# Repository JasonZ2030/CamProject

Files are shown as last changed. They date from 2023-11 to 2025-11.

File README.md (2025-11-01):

# Underwater Fishing Camera

## Introduction

As a shore angler, I've spent countless hours casting my line, waiting for bites that never came. The frustrating reality? I often had no idea if there were even any fish where I was casting. It didn't matter how good my lure was or how expensive my bait – if the fish weren't there, I wasn't catching anything.

Unlike anglers with boats who can afford expensive sonar fishfinders, I needed a budget-friendly solution that would work from the shore. That's when the idea hit me: why not create a small underwater camera that I could attach to my fishing line? This way, I could scout locations before wasting time fishing in empty water.

## Photos
<div style="display: flex; justify-content: space-around; margin: 20px 0;">
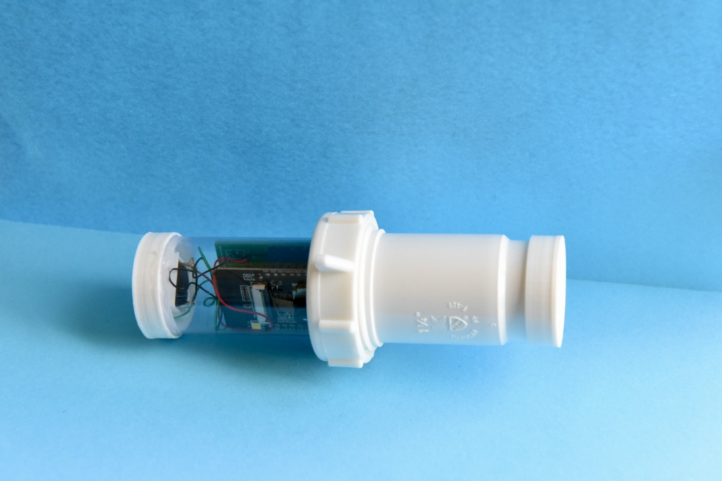
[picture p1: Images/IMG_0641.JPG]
  
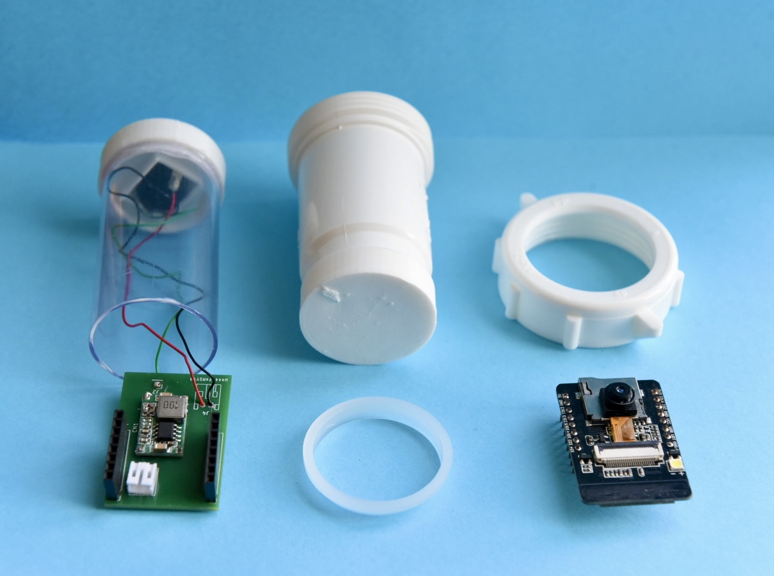
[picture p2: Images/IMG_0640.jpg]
  
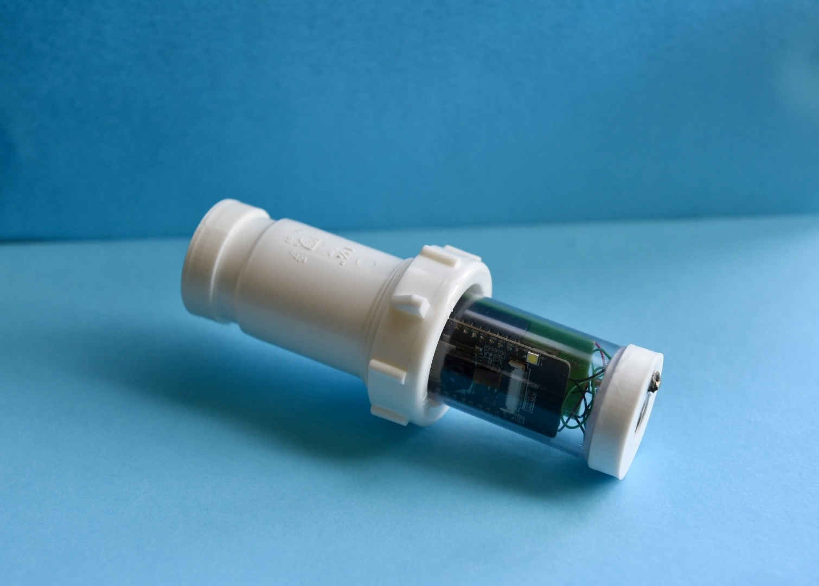
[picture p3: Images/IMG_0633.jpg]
  
</div>

## Why ESP32-CAM?

The ESP32-CAM module was the perfect choice for this project. Its compact size makes it ideal for attaching to a fishing line without adding too much weight or bulk that would interfere with casting. The module is also incredibly easy to program, with built-in WiFi capabilities that allow real-time video streaming directly to my phone.

Compared to other camera solutions, the ESP32-CAM offered the best balance of:
- **Size**: Small enough to attach to fishing gear
- **Cost**: Affordable for a DIY project
- **Functionality**: Built-in camera and WiFi in one module
- **Ease of use**: Well-documented and beginner-friendly

<div style="display: flex; justify-content: space-around; margin: 20px 0;">
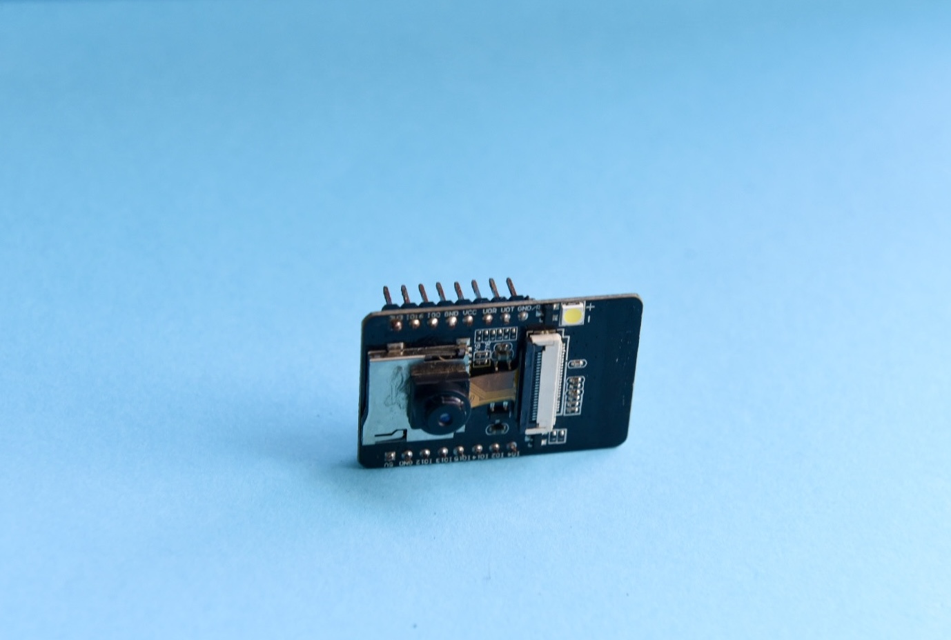
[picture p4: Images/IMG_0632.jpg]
  
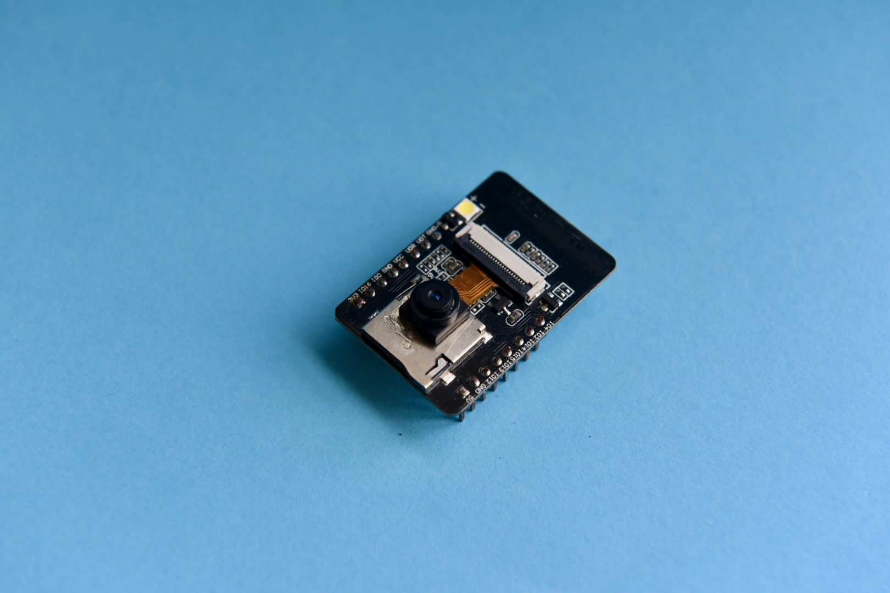
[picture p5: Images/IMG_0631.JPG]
  
</div>

### Key Features
- Automatic recording triggered by water submersion
- Waterproof housing rated for freshwater fishing depths
- External power button (no need to open case)
- Removable battery compartment for quick swaps
- Compact design attachable to fishing line

## Design Challenges & Solutions

Building this underwater camera presented three major challenges that required creative engineering solutions:

### Challenge 1: Power Supply

The ESP32-CAM requires a stable 5-volt power supply, but standard batteries don't provide this exact voltage. I needed a compact, affordable power solution that could fit inside a waterproof housing.

**Solution: Custom PCB with Voltage Regulation**

I taught myself KiCAD and designed a custom printed circuit board to solve this problem. The PCB design included:
- A socket for a standard 9V battery (the most cost-effective option)
- An integrated voltage converter to step down from 9V to the required 5V
- A soldered outlet to securely attach the 9V battery
- Direct connection to the ESP32-CAM module

This custom board became the backbone of the entire system, efficiently powering the camera while keeping costs low.

<div style="display: flex; justify-content: space-around; margin: 20px 0;">
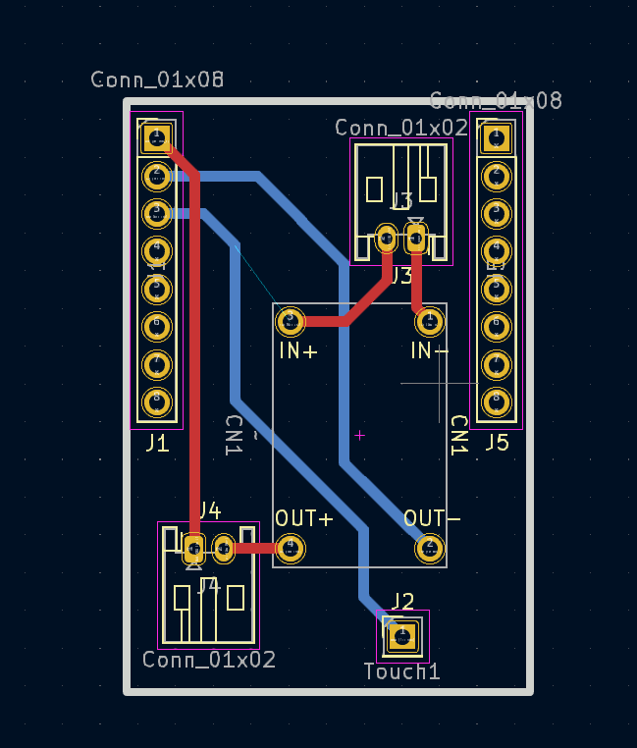
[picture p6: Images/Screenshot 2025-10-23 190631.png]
  
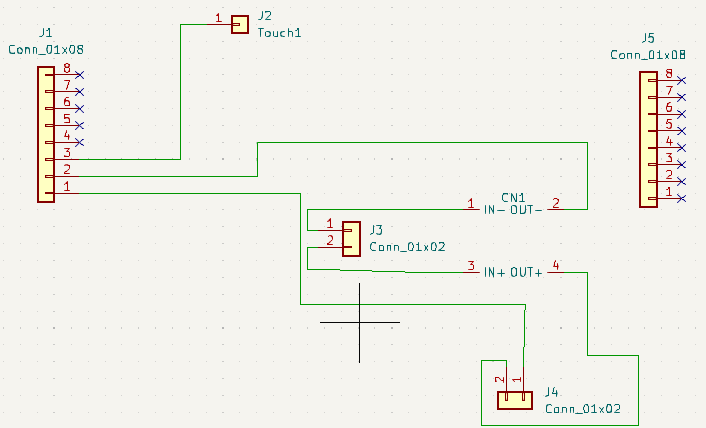
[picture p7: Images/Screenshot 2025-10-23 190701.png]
  
</div>
<div>
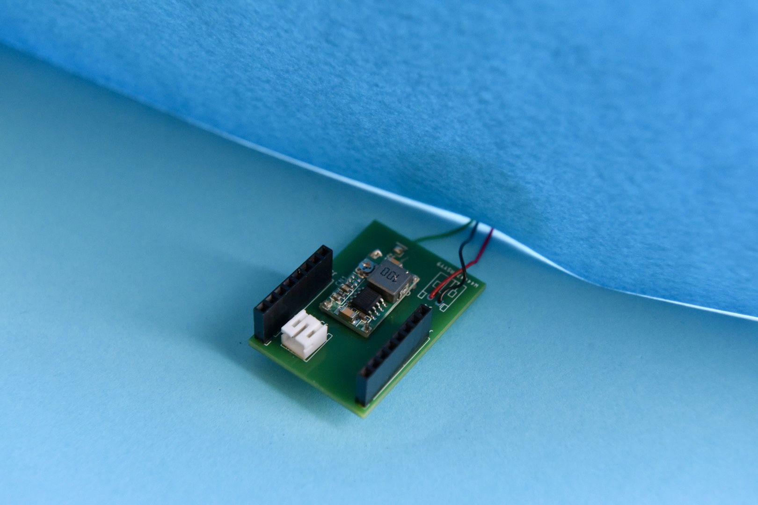
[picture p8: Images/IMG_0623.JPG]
  
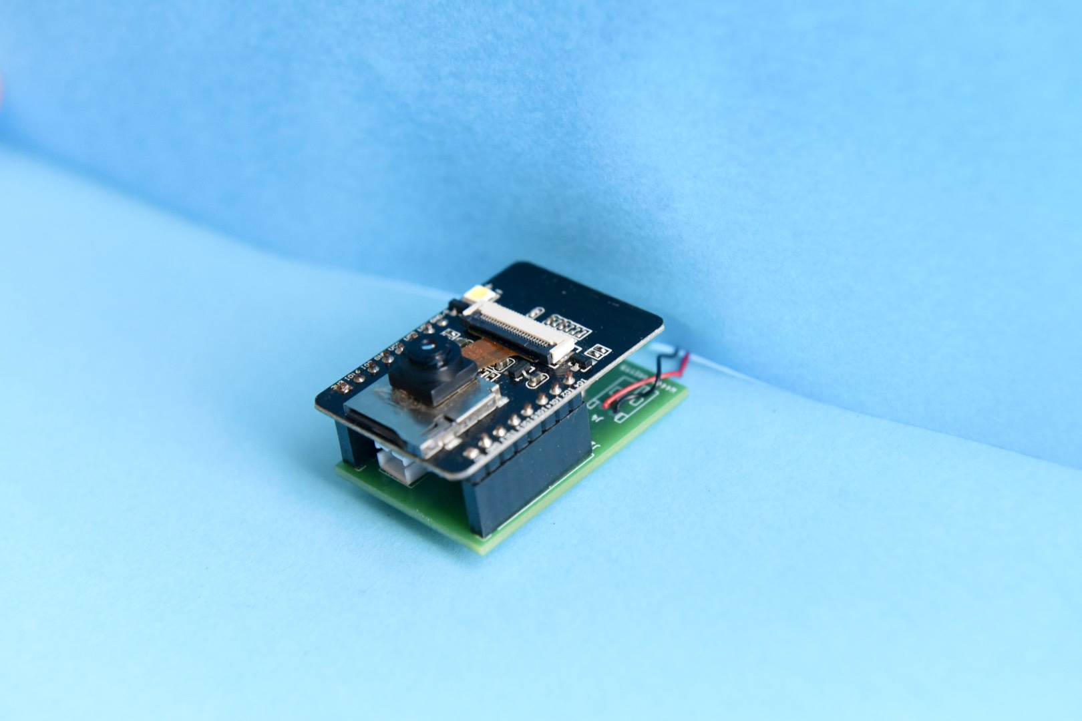
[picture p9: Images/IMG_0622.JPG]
  
</div>
  
### Challenge 2: Waterproof Control Interface

Opening a watertight case every time I needed to power on the camera or start recording would be impractical and risk water damage. I needed external controls that maintained the waterproof seal.

**Solution: Waterproof Button and Water-Sensing Trigger**

I used a clear PVC pipe as the main housing, cut to the appropriate length with caps on both ends. For the control interface:

**Power Button:**
- Created a groove in one end cap for a button soldered directly to the PCB
- Applied a silicon coating over the button for waterproofing
- Applied a layer of rubber on top of the button 
- Added an outer cap that compressed the rubber and with an opening that allows the button to be pressed while maintaining the seal
- This allows powering the camera on/off without opening the case

**Automatic Recording Trigger:**
- Installed a steel pin that protrudes through the case (fully waterproofed)
- Connected the pin to the ESP32-CAM's input pins via the PCB
- When submerged, water conductivity creates a small current between the pin and ground
- The ESP32 detects this current and automatically starts recording
- This eliminates the need for manual recording activation once underwater

<div>
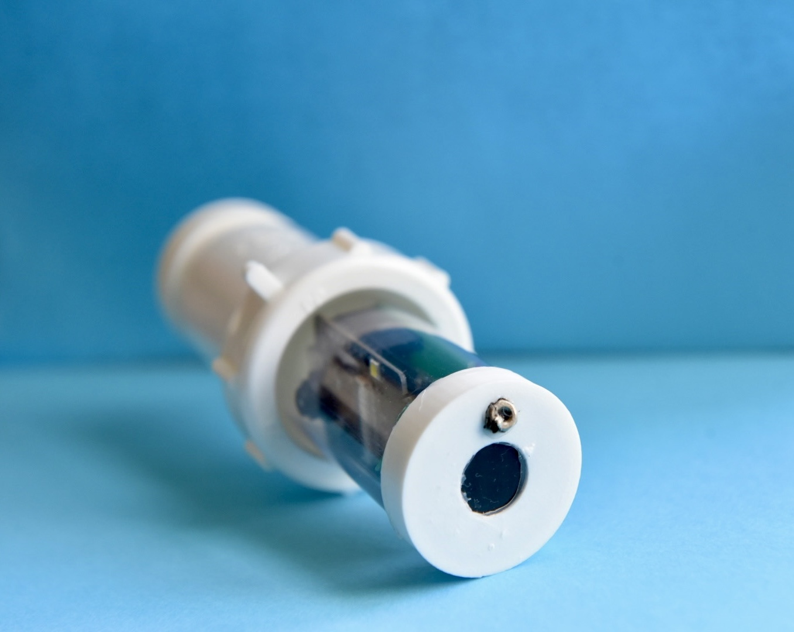
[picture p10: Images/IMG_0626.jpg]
  
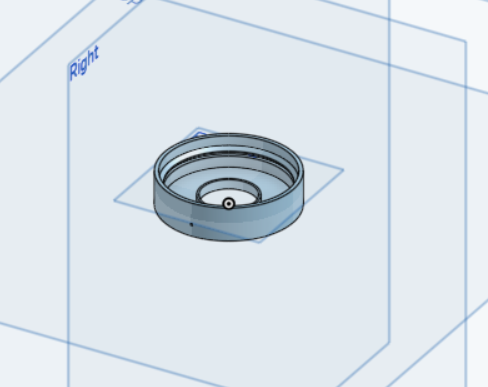
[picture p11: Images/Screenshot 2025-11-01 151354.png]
  
</div>

<div>
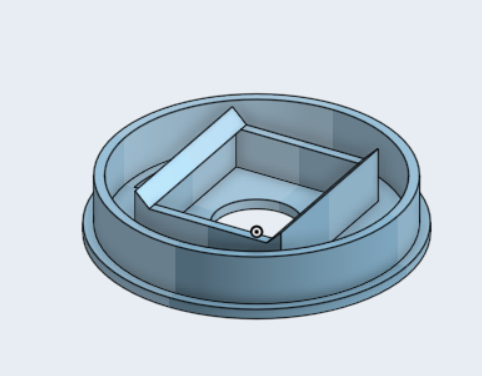
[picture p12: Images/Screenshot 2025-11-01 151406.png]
  
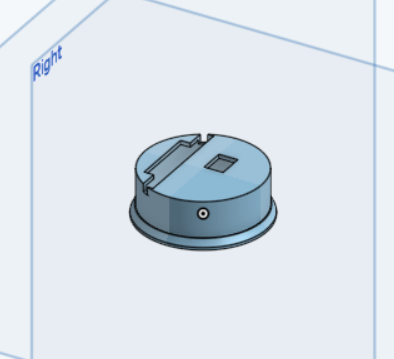
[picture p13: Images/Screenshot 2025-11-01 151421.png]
  
</div>

### Challenge 3: Battery Access and Replacement

While the main housing needed to remain sealed during use, I still needed a way to easily replace the 9V battery when it ran out, without compromising the waterproof integrity of the camera compartment.

**Solution: Screw-On Battery Compartment**

On the opposite end from the control button, I designed a removable battery compartment:
- Attached a tubular screw mechanism to the main PVC pipe
- Added a separate end cap that screws onto this mechanism
- Applied waterproof sealant to the threads for a watertight seal
- Inside this compartment, I installed the wiring and soldered the 9V battery socket
- The compartment can be unscrewed for battery replacement, then securely resealed

This design allows quick battery swaps without exposing the sensitive electronics in the main camera housing.

<div>
  
</div>

## Version 1: Proof of Concept

The first version wasn't pretty, but it worked. It was proof that the idea could be made. We had a waterproof underwater camera that could be attached to a fishing line, powered by an affordable battery system, and controlled without opening the case. While the aesthetics and refinement would come later, V1 successfully demonstrated that I could scout fishing spots from shore without expensive equipment.

<div style="display: flex; justify-content: space-around; margin: 20px 0;">
  
</div>

## Future Improvements

### Weight Distribution & Buoyancy
The camera doesn't balance well underwater because the heavy battery pulls it to one side, and air gets trapped unevenly in the case. Future versions will move parts around and balance the weight better so it floats straight.

### Live WiFi Video Streaming
Add live video streaming to a phone so I can see what's underwater in real-time instead of watching recorded footage later. This might need changes to how the camera is set up to get the WiFi signal working through water.

### Reverse-Facing Camera
Flip the camera around so it points backward. This way I can watch my lure as I reel it in and see how fish react to it, which helps me figure out what makes them bite.

### Size & Weight Reduction
Make the whole thing smaller and lighter by redesigning the circuit board to be more compact, switching to lighter batteries, and using a thinner case. This will make it easier to cast and attach to my fishing line.
## Contributing

If you are interested in improving the design or have suggestions, feel free to open an issue or submit a pull request!

## Contact

**Name**: Jason Zhang

**Email**: jason.zhang.duidui@gmail.com

---

*Built with passion for fishing and engineering*

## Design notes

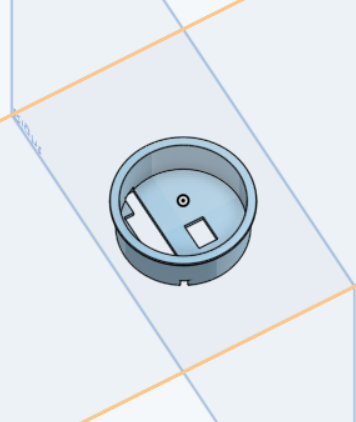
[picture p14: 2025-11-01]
Images/Screenshot 2025-11-01 151429.png

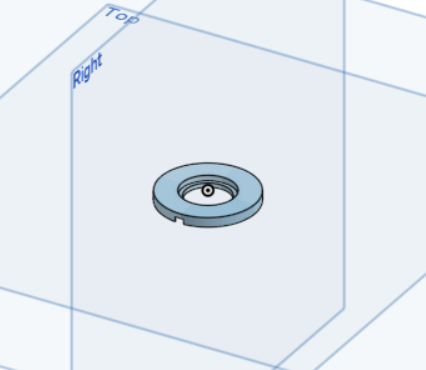
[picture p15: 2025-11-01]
Images/Screenshot 2025-11-01 151345.png

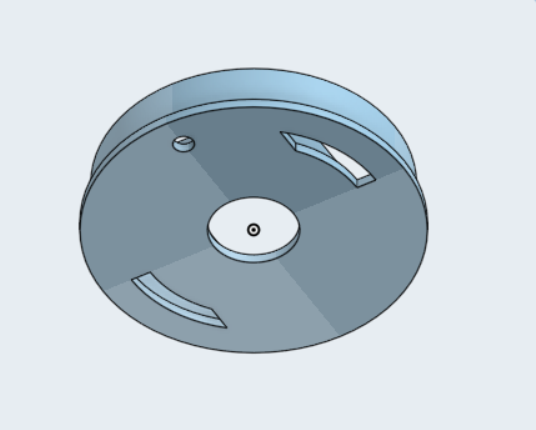
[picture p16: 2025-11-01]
Images/Screenshot 2025-11-01 151414.png

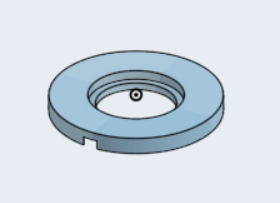
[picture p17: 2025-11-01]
Images/Screenshot 2025-11-01 151257.png

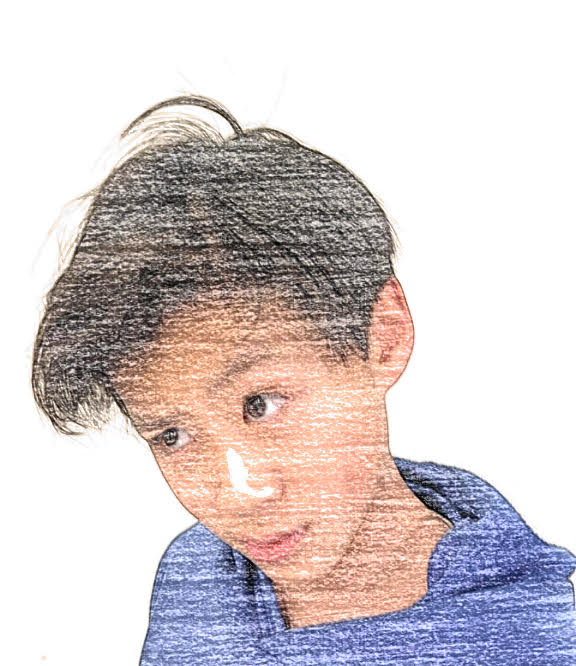
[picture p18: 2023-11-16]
Images/unnamed.jpg

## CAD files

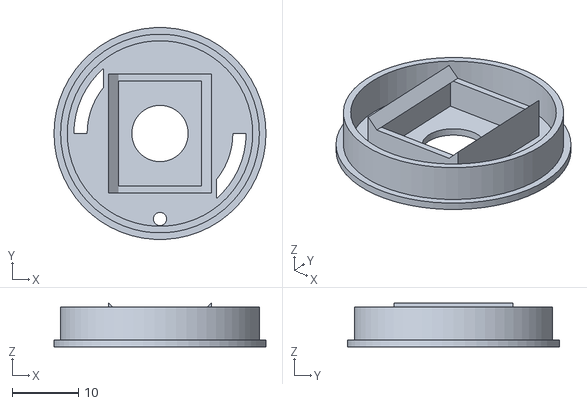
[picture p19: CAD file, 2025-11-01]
3D Models/Button Switch Cap.stl
32.0 x 32.0 x 6.60

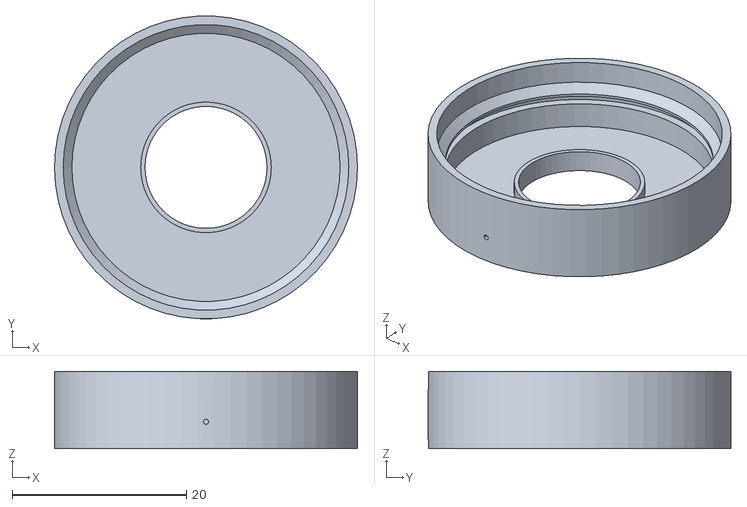
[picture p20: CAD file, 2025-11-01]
3D Models/Outer Push Button Cap.stl
34.8 x 34.8 x 8.90

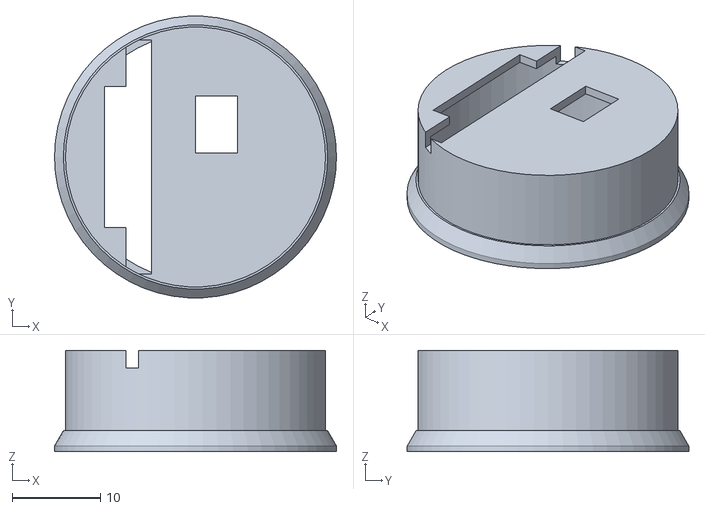
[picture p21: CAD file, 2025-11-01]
3D Models/SD-battery Cap.stl
32.0 x 32.0 x 11.5

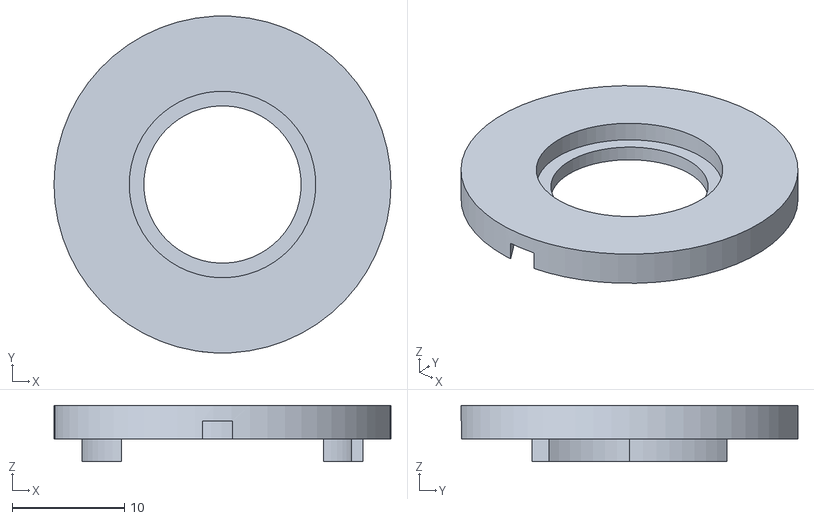
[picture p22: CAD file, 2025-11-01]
3D Models/Rubber Button Compressor.stl
30.0 x 30.0 x 5.00

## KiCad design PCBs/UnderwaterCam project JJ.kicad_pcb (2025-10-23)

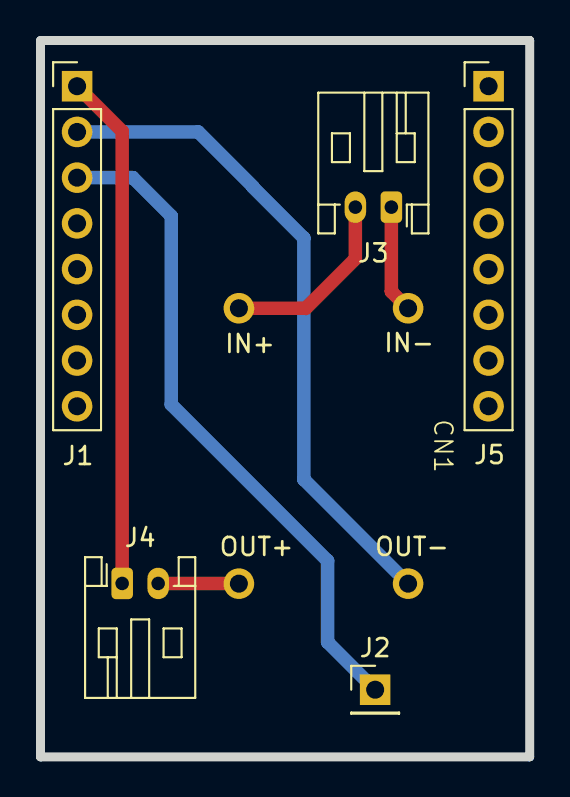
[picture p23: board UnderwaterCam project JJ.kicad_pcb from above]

Board: 2 copper layers, 27.2 x 39.8 mm, 6 parts (0 on the bottom side), 5 nets.

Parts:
CN1: PowerSupplyConn
J1, J5: Conn_01x08; PinHeader_1x08_P2.54mm_Vertical
J2: Touch1; PinHeader_1x01_P2.54mm_Vertical
J3, J4: Conn_01x02; JST_PH_S2B-PH-K_1x02_P2.00mm_Horizontal

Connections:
unnamed: CN1.3 (IN+), J1.3, J2.1, J3.2
unnamed: CN1.1 (IN-), J3.1
unnamed: CN1.4 (OUT+), J4.2
unnamed: CN1.2 (OUT-), J1.2
unnamed: J1.1, J4.1

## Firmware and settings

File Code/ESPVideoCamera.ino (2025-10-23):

// -----------------------------------------------------------------------------------------
// Program:  ESPVideoCamera 
// Summary:  T5 capacitor touch pin trigger video camera that saves AVI files to SD card.
// Author:   JasonZ
//           
// Future:   Play around with the camera settings to get best picture quality.
//           Create custom PCB to hold ESP32-CAM, PIR sensor, & 3.3v power supply.                 
// 
// Overview:
//  Based on ESP32-CAM AI Thinker board. 
//  Uses both cores of the ESP32.
//   Core 0 is used to: check the motion sensor to trigger capturing frames and storing them in memory.
//   Core 1 is used to: retrieve frames from memory and create the AVI file on the SD card.
//  The on board flash LED is (stupidly) connected to GPIO4.  This pin is used by the SD card so will flash when accessing - recommend disconnecting the driving transistor.
//  PIR sensor is connected to GPIO12(T5).  This is the RX for the serial connection.  The sensor should be disconnected when uploding the sketch to avoid issues.
//  I decided to go with S-VGA (800x600) resolution rather the XUGA (1600x1200) to be able to handle more fps, and ceate smaller files on the SD card.
// 
//  It is useful to understand the AVI file format - Below is a summary (based on my understanding).
//  There are a number of fields in the file that need to be updated once sizes are known - these are highlighted below. 
//
// +-- RIFF, sz, AVI --------+ sz = total file size - 8 bytes (updated at EOF)
// | +-- LIST, 68, hdrl ---+ | 
// | | +--- avih, 56 --+   | |
// | | |               |   | |
// | | + --------------+   | |
// | +---------------------+ |
// |                         |
// | +-- LIST, 144, strl --+ | 
// | | +-- strh, 48 --+    | |
// | | |              |    | | dwlength = fileFramesWritten (updated at EOF)
// | | +--------------+    | |
// | | +-- strf, 40 --+    | |
// | | |              |    | |
// | | +--------------+    | |
// | | +-- INFO, 28 --+    | |
// | | |              |    | |
// | | +--------------+    | |
// | +---------------------+ |
// |                         |
// | +-- LIST, sz, movi ---+ | sz = fileFramesTotalSize + (8 * fileFramesWritten) + sum of padding (updated at EOF)
// | | +-- 00dc, sz --+    | | sz = frameBuffer[]->len + padding.
// | | | frame 1      |    | |  
// | | |              |    | |
// | | | padding      |    | | Each data chunk (00dc) must finish on a 2 byte boundary, so 1 extra byte might be required.
// | | +--------------+    | |
// | | . . .               | |
// | | +-- 00dc, sz --+    | |
// | | | frame x      |    | |
// | | |              |    | |
// | | | padding      |    | |
// | | +--------------+    | |
// | +---------------------+ |
// |                         |
// | +-- idx1, sz ---------+ | sz = fileFramesWritten * 16 (this entire section gets written at EOF)
// | | +-- frame 1 --+     | |  
// | | | offset      |     | | offset points to 00dc, and is relative to start of movi. First frame offset 0x00. 
// | | | sz          |     | | sz = frameBuffer[]->len.  Padding is not included.
// | | |             |     | |
// | | +-------------+     | |
// | | . . .               | |
// | | +-- frame x --+     | |
// | | |             |     | |
// | | +-------------+     | |
// | +---------------------+ |
// +-------------------------+
//
// Useful references:
//  https://docs.microsoft.com/en-us/windows/win32/directshow/avi-riff-file-reference
//  https://www.klennet.com/notes/2021-09-03-carving-avi-files.aspx
//  https://www.fileformat.info/format/riff/egff.htm
//  http://graphcomp.com/info/specs/ms/editmpeg.htm
//  https://cdn.hackaday.io/files/274271173436768/avi.pdf
//  https://www.opennet.ru/docs/formats/avi.txt
//  https://www.tutorialspoint.com/esp32_for_iot/esp32_for_iot_getting_current_time_using_ntp_client.htm
//

#include "esp_camera.h"                      // Camera library
#include "esp_vfs_fat.h"                     // SD card library
#include <EEPROM.h>                          // Used to store the file number.
 
#include <WiFi.h>                            // Used to connect to WiFi to get the time via NTP.
//#include <ESP32Time.h>                       // Used to set the internal RTC, so the timestamp of AVI files is correct.
#include "driver/sdmmc_host.h"
#include "driver/sdspi_host.h"

#define PWDN_GPIO_NUM     32                 // Pins for CAMERA_MODEL_AI_THINKER
#define RESET_GPIO_NUM    -1                 //
#define XCLK_GPIO_NUM      0                 //
#define SIOD_GPIO_NUM     26                 //
#define SIOC_GPIO_NUM     27                 //
#define Y9_GPIO_NUM       35                 //
#define Y8_GPIO_NUM       34                 //
#define Y7_GPIO_NUM       39                 //
#define Y6_GPIO_NUM       36                 //
#define Y5_GPIO_NUM       21                 //
#define Y4_GPIO_NUM       19                 //
#define Y3_GPIO_NUM       18                 //
#define Y2_GPIO_NUM        5                 //
#define VSYNC_GPIO_NUM    25                 //
#define HREF_GPIO_NUM     23                 //
#define PCLK_GPIO_NUM     22                 //

#define EEPROM_SIZE        2                 // Size of EEPROM used (holds last used file number, max 65,535).

const uint16_t      AVI_HEADER_SIZE = 252;   // Size of the AVI file header.
const int           SENSOR_PIN      = 3;     // GPIO3 connected to the PIR sensor.  This is also used as U0RXD but isn't required when the program is running. 
const long unsigned SENSOR_INTERVAL = 500;   // Time (ms) between motion sensor checks 
const long unsigned MOTION_DELAY    = 25000; // Time (ms) after motion last detected that we keep recording

const long unsigned FRAME_INTERVAL  = 250;   // Time (ms) between frame captures 
const uint8_t       JPEG_QUALITY    = 10;    // JPEG quality (0-63).
const uint8_t       MAX_FRAMES      = 10;    // Maximum number of frames we hold at any time


const long unsigned WIFI_TIMEOUT    = 20000; // Try to connect to WiFi for this long, then give up.

const byte buffer00dc   [4]  = {0x30, 0x30, 0x64, 0x63}; // "00dc"
const byte buffer0000   [4]  = {0x00, 0x00, 0x00, 0x00}; // 0x00000000
const byte bufferAVI1   [4]  = {0x41, 0x56, 0x49, 0x31}; // "AVI1"            
const byte bufferidx1   [4]  = {0x69, 0x64, 0x78, 0x31}; // "idx1" 

                               
const byte aviHeader[AVI_HEADER_SIZE] =      // This is the AVI file header.  Some of these values get overwritten.
{
  0x52, 0x49, 0x46, 0x46,  // 0x00 "RIFF"
  0x00, 0x00, 0x00, 0x00,  // 0x04           Total file size less 8 bytes [gets updated later] 
  0x41, 0x56, 0x49, 0x20,  // 0x08 "AVI "

  0x4C, 0x49, 0x53, 0x54,  // 0x0C "LIST"
  0x44, 0x00, 0x00, 0x00,  // 0x10 68        Structure length
  0x68, 0x64, 0x72, 0x6C,  // 0x04 "hdrl"

  0x61, 0x76, 0x69, 0x68,  // 0x08 "avih"    fcc
  0x38, 0x00, 0x00, 0x00,  // 0x0C 56        Structure length
  0x90, 0xD0, 0x03, 0x00,  // 0x20 250000    dwMicroSecPerFrame     [based on FRAME_INTERVAL] 
  0x00, 0x00, 0x00, 0x00,  // 0x24           dwMaxBytesPerSec       [gets updated later] 
  0x00, 0x00, 0x00, 0x00,  // 0x28 0         dwPaddingGranularity
  0x10, 0x00, 0x00, 0x00,  // 0x2C 0x10      dwFlags - AVIF_HASINDEX set.
  0x00, 0x00, 0x00, 0x00,  // 0x30           dwTotalFrames          [gets updated later]
  0x00, 0x00, 0x00, 0x00,  // 0x34 0         dwInitialFrames (used for interleaved files only)
  0x01, 0x00, 0x00, 0x00,  // 0x38 1         dwStreams (just video)
  0x00, 0x00, 0x00, 0x00,  // 0x3C 0         dwSuggestedBufferSize
  0x20, 0x03, 0x00, 0x00,  // 0x40 800       dwWidth - 800 (S-VGA)  [based on FRAMESIZE] 
  0x58, 0x02, 0x00, 0x00,  // 0x44 600       dwHeight - 600 (S-VGA) [based on FRAMESIZE]      
  0x00, 0x00, 0x00, 0x00,  // 0x48           dwReserved
  0x00, 0x00, 0x00, 0x00,  // 0x4C           dwReserved
  0x00, 0x00, 0x00, 0x00,  // 0x50           dwReserved
  0x00, 0x00, 0x00, 0x00,  // 0x54           dwReserved

  0x4C, 0x49, 0x53, 0x54,  // 0x58 "LIST"
  0x84, 0x00, 0x00, 0x00,  // 0x5C 144
  0x73, 0x74, 0x72, 0x6C,  // 0x60 "strl"

  0x73, 0x74, 0x72, 0x68,  // 0x64 "strh"    Stream header
  0x30, 0x00, 0x00, 0x00,  // 0x68  48       Structure length
  0x76, 0x69, 0x64, 0x73,  // 0x6C "vids"    fccType - video stream
  0x4D, 0x4A, 0x50, 0x47,  // 0x70 "MJPG"    fccHandler - Codec
  0x00, 0x00, 0x00, 0x00,  // 0x74           dwFlags - not set
  0x00, 0x00,              // 0x78           wPriority - not set
  0x00, 0x00,              // 0x7A           wLanguage - not set
  0x00, 0x00, 0x00, 0x00,  // 0x7C           dwInitialFrames
  0x01, 0x00, 0x00, 0x00,  // 0x80 1         dwScale
  0x04, 0x00, 0x00, 0x00,  // 0x84 4         dwRate (frames per second)         [based on FRAME_INTERVAL]         
  0x00, 0x00, 0x00, 0x00,  // 0x88           dwStart               
  0x00, 0x00, 0x00, 0x00,  // 0x8C           dwLength (frame count)             [gets updated later]
  0x00, 0x00, 0x00, 0x00,  // 0x90           dwSuggestedBufferSize
  0x00, 0x00, 0x00, 0x00,  // 0x94           dwQuality
  0x00, 0x00, 0x00, 0x00,  // 0x98           dwSampleSize

  0x73, 0x74, 0x72, 0x66,  // 0x9C "strf"    Stream format header
  0x28, 0x00, 0x00, 0x00,  // 0xA0 40        Structure length
  0x28, 0x00, 0x00, 0x00,  // 0xA4 40        BITMAPINFOHEADER length (same as above)
  0x20, 0x03, 0x00, 0x00,  // 0xA8 800       Width                  [based on FRAMESIZE] 
  0x58, 0x02, 0x00, 0x00,  // 0xAC 600       Height                 [based on FRAMESIZE] 
  0x01, 0x00,              // 0xB0 1         Planes  
  0x18, 0x00,              // 0xB2 24        Bit count (bit depth once uncompressed)                   
  0x4D, 0x4A, 0x50, 0x47,  // 0xB4 "MJPG"    Compression 
  0x00, 0x00, 0x04, 0x00,  // 0xB8 262144    Size image (approx?)                              [what is this?]
  0x00, 0x00, 0x00, 0x00,  // 0xBC           X pixels per metre 
  0x00, 0x00, 0x00, 0x00,  // 0xC0           Y pixels per metre
  0x00, 0x00, 0x00, 0x00,  // 0xC4           Colour indices used  
  0x00, 0x00, 0x00, 0x00,  // 0xC8           Colours considered important (0 all important).


  0x49, 0x4E, 0x46, 0x4F, // 0xCB "INFO"
  0x1C, 0x00, 0x00, 0x00, // 0xD0 28         Structure length
  0x70, 0x61, 0x75, 0x6c, // 0xD4 
  0x2e, 0x77, 0x2e, 0x69, // 0xD8 
  0x62, 0x62, 0x6f, 0x74, // 0xDC 
  0x73, 0x6f, 0x6e, 0x40, // 0xE0 
  0x67, 0x6d, 0x61, 0x69, // 0xE4 
  0x6c, 0x2e, 0x63, 0x6f, // 0xE8 
  0x6d, 0x00, 0x00, 0x00, // 0xEC 

  0x4C, 0x49, 0x53, 0x54, // 0xF0 "LIST"
  0x00, 0x00, 0x00, 0x00, // 0xF4           Total size of frames        [gets updated later]
  0x6D, 0x6F, 0x76, 0x69  // 0xF8 "movi"
};

// Following the header above are each of the frames.  Each one consists of
//  "00dc"      Stream 0, Uncompressed DIB format.
//   0x00000000 Length of frame
//   Frame      then the rest of the frame data received from the camera (note JFIF in the frame data gets overwritten with AVI1) 
//   0x00       we also potentially add a padding byte to ensure the frame chunk is an even number of bytes.
//
// At the end of the file we add an idx1 index section.  Details in closeFile() routine.
 


camera_fb_t *frameBuffer[MAX_FRAMES];      // This is where we hold references to the captured frames in a circular buffer.
                                           // typedef struct 
                                           // {
                                           //   uint8_t *buf;         Pointer to the pixel data 
                                           //   size_t len;           Length of the buffer in bytes 
                                           //   size_t width;         Width of the buffer in pixels 
                                           //   size_t height;        Height of the buffer in pixels 
                                           //   pixformat_t format;   Format of the pixel data 
                                           // } camera_fb_t;
                                           
uint8_t  frameInPos  = 0;                  // Position within buffer where we write to.
uint8_t  frameOutPos = 0;                  // Position within buffer where we read from.
                                       
                                           // The following relate to the AVI file that gets created.
uint16_t fileFramesCaptured  = 0;          // Number of frames captured by camera.
uint16_t fileFramesWritten   = 0;          // Number of frames written to the AVI file.
uint32_t fileFramesTotalSize = 0;          // Total size of frames in file.
uint32_t fileStartTime       = 0;          // Used to calculate FPS. 
uint32_t filePadding         = 0;          // Total padding in the file.  

                                           // These 2 variable conrtol the camera, and the actions required each processing loop. 
boolean motionDetected  = false;           // This is set when motion is detected.  It stays set for MOTION_DELAY ms after motion stops.
boolean fileOpen        = false;           // This is set when we have an open AVI file.

FILE *aviFile;                             // AVI file
FILE *idx1File;                            // Temporary file used to hold the index information   
 
TaskHandle_t Core0Task;                    // freeRTOS task handler for core 0
TaskHandle_t Core1Task;                    // freeRTOS task handler for core 1

enum relative                              // Used when setting position within a file stream.
{
  FROM_START,
  FROM_CURRENT,
  FROM_END
};

//ESP32Time rtc;


void setup()
{
  // Initialise serial monitor.
  Serial.begin(115200);
  while(!Serial);

  pinMode(33, OUTPUT);
  pinMode(4, OUTPUT);
  digitalWrite(33, HIGH);   // turn the LED off (HIGH is the voltage level)
  // Initialise EEPROM - used to hold file number used in the avi file names.
  EEPROM.begin(EEPROM_SIZE);


  // Initialise the SD card.
  initialiseSDCard();


  // Initialise the camera.
  initialiseCamera(); 


  // Get the current time from the Internet and initialise the ESP32's RTC. 
  // This is not essential, and this can be commented out if not required.  The only impact is
  // the files created will not have the correct timestamp.
  //initialiseTime();
  

  // Set up the task handlers on each core.
  xTaskCreatePinnedToCore(codeCore0Task, "Core0Task", 8192, NULL, 5, &Core0Task, 0);
  xTaskCreatePinnedToCore(codeCore1Task, "Core1Task", 8192, NULL, 5, &Core1Task, 1);

  blinkFlash(3);
}



// ------------------------------------------------------------------------------------------
// loop not used as all code runs via freeRTOS task handers.
// ------------------------------------------------------------------------------------------

void loop()
{
  
}



// ------------------------------------------------------------------------------------------
// Core 0 is used to capture frames, and check the motion sensor.
// ------------------------------------------------------------------------------------------

void codeCore0Task(void *parameter)
{
  unsigned long currentMillis    = 0; // Current time
  unsigned long lastSensorCheck  = 0; // Last time we checked the motion sensor
  unsigned long lastPictureTaken = 0; // Last time we captured a frame
  unsigned long lastMotion       = 0; // Last time we detected movement

    
  for (;;)
  {
    currentMillis = millis();

    // Check for movement every SENSOR_INTERVAL ms.
    if (currentMillis - lastSensorCheck > SENSOR_INTERVAL)
    {
      lastSensorCheck = currentMillis;
      
   
      // Check the sensor.
      //if (digitalRead(SENSOR_PIN) == HIGH)                  // Current movement
      if(touchRead(T5) < 40)
      {
        if (!motionDetected)
          Serial.println("Movement detected.");
        lastMotion = currentMillis;
        motionDetected = true;
      }  
      else if (lastMotion == 0)                             // Never any movement (i.e. at startup)
        motionDetected = false;   
      else if (currentMillis - lastMotion < MOTION_DELAY)   // Recent movement
        motionDetected = true;         
      else
        motionDetected = false;                             // No recent movement
    }


    // If we need to, capture a frame every FRAME_INTERVAL ms.
    if (motionDetected && currentMillis - lastPictureTaken > FRAME_INTERVAL)
    {
      lastPictureTaken = currentMillis;

      captureFrame();
    }

    delay(1);
  }
}



// ------------------------------------------------------------------------------------------
// Core 1 is used to write the frames captured to the AVI file.
// ------------------------------------------------------------------------------------------

void codeCore1Task(void *parameter)
{
  for (;;)
  { 
    // Once motion is detected we open a new file.
    if (motionDetected && !fileOpen) {
      startFile();
      digitalWrite(33,LOW);   // turn the LED on (HIGH is the voltage level)
    }

    // If there are frames waiting to be processed add these to the file.
    if (motionDetected && fileOpen && framesInBuffer() > 0) {
      addToFile();
    }

    // Once motion stops, add any remaining frames to the file, and close the file.
    if (!motionDetected && fileOpen){
      closeFile();
      digitalWrite(33, HIGH);   // turn the LED off (HIGH is the voltage level)
      Serial.println("closed file");
    }
    
    delay(1);
  }
}



// ------------------------------------------------------------------------------------------
// Setup the camera.
// ------------------------------------------------------------------------------------------

void initialiseCamera()
{
  Serial.println("Initialising camera");
  
  camera_config_t config;

  config.ledc_channel = LEDC_CHANNEL_0;
  config.ledc_timer   = LEDC_TIMER_0;
  config.pin_d0       = Y2_GPIO_NUM;
  config.pin_d1       = Y3_GPIO_NUM;
  config.pin_d2       = Y4_GPIO_NUM;
  config.pin_d3       = Y5_GPIO_NUM;
  config.pin_d4       = Y6_GPIO_NUM;
  config.pin_d5       = Y7_GPIO_NUM;
  config.pin_d6       = Y8_GPIO_NUM;
  config.pin_d7       = Y9_GPIO_NUM;
  config.pin_xclk     = XCLK_GPIO_NUM;
  config.pin_pclk     = PCLK_GPIO_NUM;
  config.pin_vsync    = VSYNC_GPIO_NUM;
  config.pin_href     = HREF_GPIO_NUM;
  config.pin_sscb_sda = SIOD_GPIO_NUM;
  config.pin_sscb_scl = SIOC_GPIO_NUM;
  config.pin_pwdn     = PWDN_GPIO_NUM;
  config.pin_reset    = RESET_GPIO_NUM;
  config.pixel_format = PIXFORMAT_JPEG;  // Image format PIXFORMAT_JPEG - possibly only format supported for OV2640.  PIXFORMAT_GRAYSCALE
  
  config.xclk_freq_hz = 20000000;

                                         // The follow fields determine the size of the buffer required.
  config.frame_size   = FRAMESIZE_VGA;  //  800 x  600. 40ms capture.
  config.jpeg_quality = JPEG_QUALITY;    // 0-63.  Only relevent if PIXFORMAT_JPEG format.  Very low may cause camera to crash at higher frame sizes.
  config.fb_count     = MAX_FRAMES;      // Maximum frames (depends on frame_size, jpeg_quality, frameDelay)

  esp_err_t cam_err = esp_camera_init(&config);

  if (cam_err == ESP_OK)
  {
    Serial.println("Camera ready");    
  }
  else
  {
    Serial.print("Camera initialisation error ");
    Serial.println(esp_err_to_name(cam_err));
    fatalError();
  }


  // Some camera settings can be set using the sensor values below.
  sensor_t *s = esp_camera_sensor_get();

  s->set_brightness(s, 1);                  // -2 to 2
  s->set_contrast(s, 0);                    // -2 to 2
  s->set_saturation(s, 0);                  // -2 to 2
  s->set_special_effect(s, 0);              // Special effect.  0 - None, 1 - Negative, 2 - Grayscale, 3 - Red Tint, 4 - Green Tint, 5 - Blue Tint, 6 - Sepia
  s->set_whitebal(s, 1);                    // 0 = disable , 1 = enable
  s->set_awb_gain(s, 1);                    // 0 = disable , 1 = enable
  s->set_wb_mode(s, 0);                     // 0 to 4 - if awb_gain enabled (0 - Auto, 1 - Sunny, 2 - Cloudy, 3 - Office, 4 - Home)
  s->set_exposure_ctrl(s, 1);               // 0 = disable , 1 = enable
  s->set_aec2(s, 1);                        // 0 = disable , 1 = enable
  s->set_ae_level(s, 0);                    // -2 to 2
  s->set_aec_value(s, 300);                 // 0 to 1200
  s->set_gain_ctrl(s, 1);                   // 0 = disable , 1 = enable
  s->set_agc_gain(s, 0);                    // 0 to 30
  s->set_gainceiling(s, (gainceiling_t)0);  // 0 to 6
  s->set_bpc(s, 0);                         // 0 = disable , 1 = enable
  s->set_wpc(s, 1);                         // 0 = disable , 1 = enable
  s->set_raw_gma(s, 1);                     // 0 = disable , 1 = enable
  s->set_lenc(s, 1);                        // 0 = disable , 1 = enable
  s->set_hmirror(s, 0);                     // Horizontal mirror.  0 = disable , 1 = enable
  s->set_vflip(s, 0);                       // Vertical flip.  0 = disable , 1 = enable
  s->set_dcw(s, 1);                         // 0 = disable , 1 = enable
}



// ------------------------------------------------------------------------------------------
// Routine to capture a single frame and write to memory.
// ------------------------------------------------------------------------------------------
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

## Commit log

2025-10-30 Revise README for Underwater Fishing Camera project
    Updated the README to reflect the new project focus on an underwater fishing camera, including sections on introduction, design challenges, and solutions.
2025-11-01 Enhance README with project photos and details
    Added photos and descriptions for the underwater camera project, including features, challenges, and proof of concept.

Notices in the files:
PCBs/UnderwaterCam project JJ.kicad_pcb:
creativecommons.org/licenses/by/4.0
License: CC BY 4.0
